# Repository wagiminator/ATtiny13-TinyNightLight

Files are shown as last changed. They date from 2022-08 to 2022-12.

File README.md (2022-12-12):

# TinyNightLight - Night Light with NeoPixels
TinyNightLight is a rotary encoder controlled and battery powered nightlight with NeoPixels based on the ATtiny13A.

- Design Files (EasyEDA): https://easyeda.com/wagiminator/attiny13-tinynightlight_copy

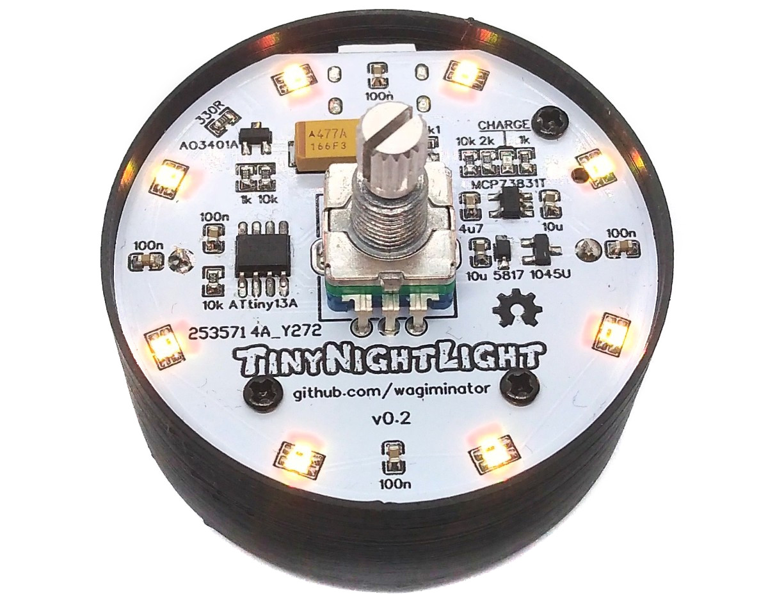
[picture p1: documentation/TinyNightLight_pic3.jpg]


# Hardware
## Schematic
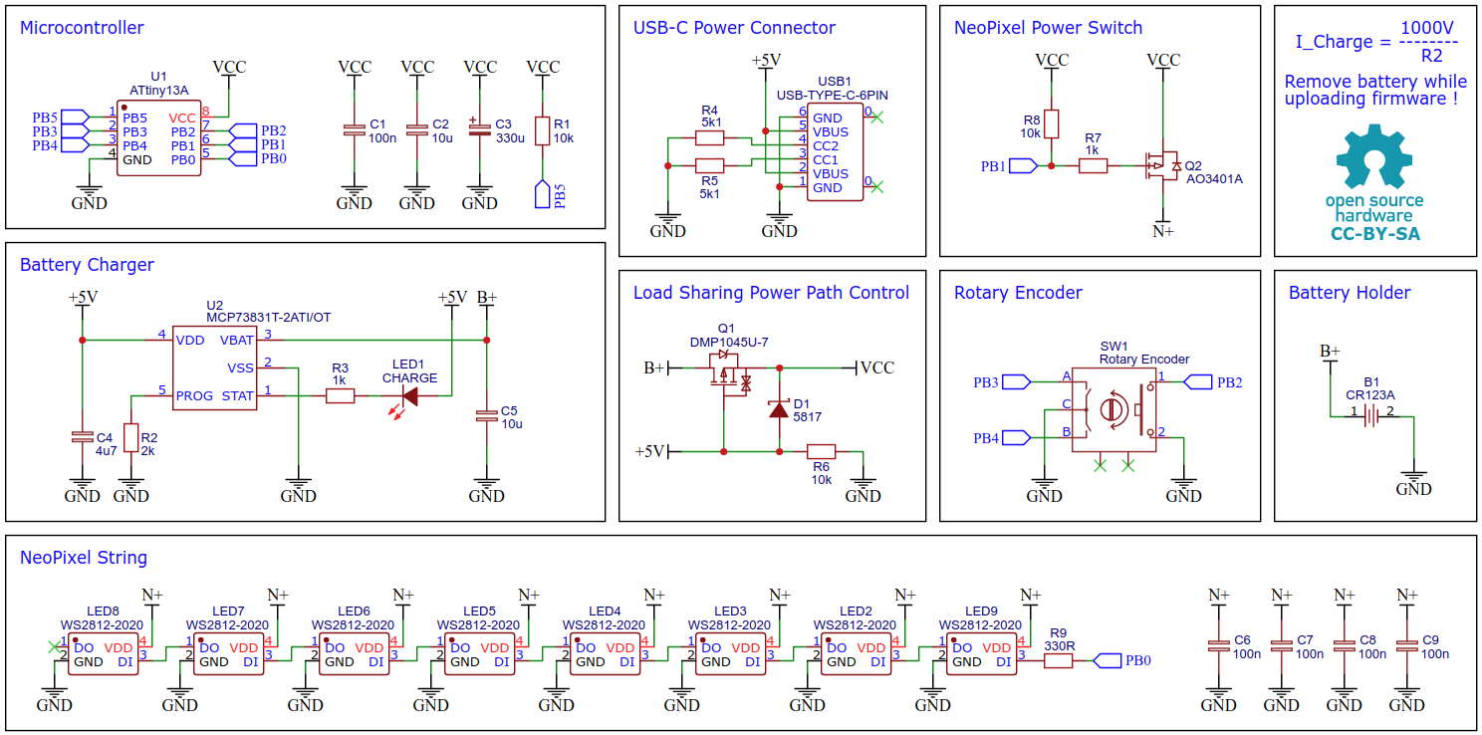
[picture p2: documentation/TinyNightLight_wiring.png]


## WS2812 Addressable LEDs
WS2812-2020 is an intelligent control LED light source, which integrates the control circuit and RGB chip in a small 2020 package. It internally contains an intelligent digital port data latch, a signal conditioning gain driver circuit, a precision oscillator and a voltage-programmable constant current control part, which effectively ensures that the pixel point light color level is consistent. Make sure you use the 5mA variant.

## MCP73831 Li-Ion Battery Charger IC
For battery charging the MCP73831 is used. The MCP73831 is a highly advanced linear charge management controller for use in space-limited, cost-sensitive applications. It employs a constant-current/constant-voltage charge algorithm with selectable preconditioning and charge termination. The constant current value is set with one external resistor (I = 1000V / R2). Charging is done via the built-in USB-C connector. The MCP73831 can be replaced by the much cheaper TP4054 without further modifications.

## Power Path Control
The device can be operated both by battery and external power. The load sharing power path control system interrupts the connection between the battery and the load when an external power supply is connected. In this case, the device is powered by the external power supply while the battery is being charged. This protects the battery and increases its lifespan. Without an external power supply, the device is powered directly by the battery.

# Software
## NeoPixel Implementation
The NeoPixel implementation is based on [NeoController](https://github.com/wagiminator/ATtiny13-NeoController).

## Compiling and Uploading the Firmware
Since there is no ICSP header on the board, you have to program the ATtiny either before soldering using an [SOP adapter](https://aliexpress.com/wholesale?SearchText=sop-8+150mil+adapter), or after soldering using an [EEPROM clip](https://aliexpress.com/wholesale?SearchText=sop8+eeprom+programming+clip). The [AVR Programmer Adapter](https://github.com/wagiminator/AVR-Programmer/tree/master/AVR_Programmer_Adapter) can help with this. Remove the battery before connecting the device to the programmer.

### If using the Arduino IDE
- Make sure you have installed [MicroCore](https://github.com/MCUdude/MicroCore).
- Go to **Tools -> Board -> MicroCore** and select **ATtiny13**.
- Go to **Tools** and choose the following board options:
  - **Clock:**  9.6 MHz internal osc.
  - **BOD:**    BOD 2.7V
  - **Timing:** Micros disabled
- Connect your programmer to your PC and to the ATtiny.
- Go to **Tools -> Programmer** and select your ISP programmer (e.g. [USBasp](https://aliexpress.com/wholesale?SearchText=usbasp)).
- Go to **Tools -> Burn Bootloader** to burn the fuses.
- Open the TinyNightLight sketch and click **Upload**.

### If using the precompiled hex-file
- Make sure you have installed [avrdude](https://learn.adafruit.com/usbtinyisp/avrdude).
- Connect your programmer to your PC and to the ATtiny.
- Open a terminal.
- Navigate to the folder with the hex-file.
- Execute the following command (if necessary replace "usbasp" with the programmer you use):
  ```
  avrdude -c usbasp -p t13 -U lfuse:w:0x3a:m -U hfuse:w:0xfb:m -U flash:w:tinynightlight.hex
  ```

### If using the makefile (Linux/Mac)
- Make sure you have installed [avr-gcc toolchain and avrdude](http://maxembedded.com/2015/06/setting-up-avr-gcc-toolchain-on-linux-and-mac-os-x/).
- Connect your programmer to your PC and to the ATtiny.
- Open a terminal.
- Navigate to the folder with the makefile and the sketch.
- Run `PROGRMR=usbasp make install` to compile, burn the fuses and upload the firmware (change PROGRMR accordingly).

# Operating Instructions
Place a 3.7V protected 16340 (LR123A) Li-Ion battery in the holder. The battery can be charged via the USB-C port. A red LED lights up during charging. It goes out when charging is complete.

The device has four different states, which can be switched between by pressing the rotary encoder button.

|State|Description|
|:-|:-|
|0|All LEDs are off and the ATtiny is in sleep mode.|
|1|All LEDs light up white. The brightness can be changed by turning the rotary encoder. The brightness set by this is also retained for the following states.|
|2|The LEDs show a color animation with the previously set brightness. The speed of the animation can be adjusted using the rotary encoder.|
|3|All LEDs show the same color with the previously set brightness. The color can be changed by turning the rotary encoder.|

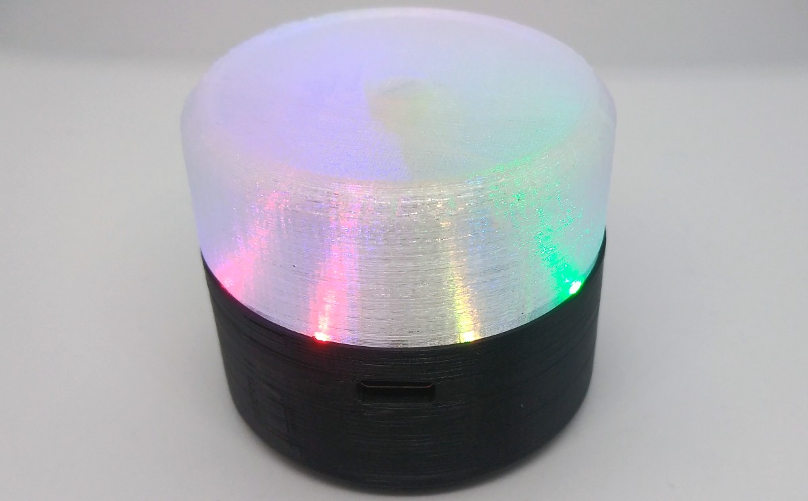
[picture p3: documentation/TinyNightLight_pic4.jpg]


# References, Links and Notes
1. [ATtiny13A Datasheet](http://ww1.microchip.com/downloads/en/DeviceDoc/doc8126.pdf)
2. [WS2812-2020 Datasheet](https://www.led-stuebchen.de/download/WS2812-2020_V1.1_EN.pdf)
3. [MCP73831 Datasheet](https://datasheet.lcsc.com/lcsc/1809191822_Microchip-Tech-MCP73831T-2ATI-OT_C14879.pdf)
4. [NeoPixel Implementation](https://github.com/wagiminator/ATtiny13-NeoController)

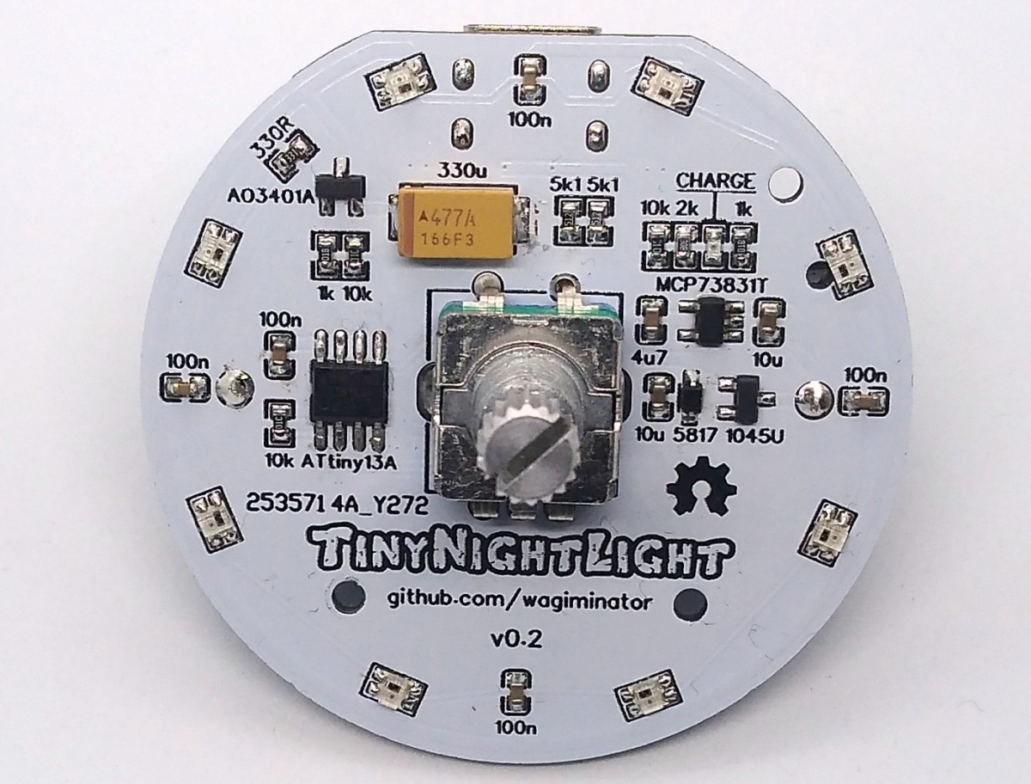
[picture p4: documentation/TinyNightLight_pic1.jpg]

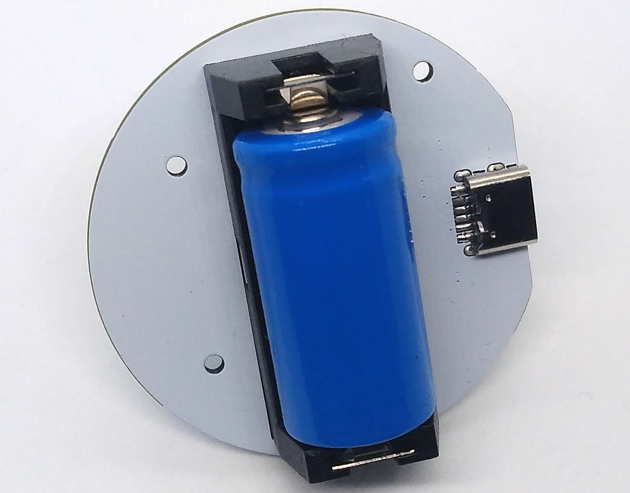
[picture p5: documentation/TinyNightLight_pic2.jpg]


# License


This work is licensed under Creative Commons Attribution-ShareAlike 3.0 Unported License. 
(http://creativecommons.org/licenses/by-sa/3.0/)

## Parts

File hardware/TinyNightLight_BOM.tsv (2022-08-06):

ID | Name | Designator | Footprint | Quantity | Manufacturer Part | Manufacturer | Supplier | Supplier Part | Price
1 | CR123A | B1 | TH_L43.0-W-18.0-CR123A | 1 | CR123A电池座 | null | LCSC | C2803347
2 | 100n | C1,C6,C7,C8,C9 | C_0603 | 5 | CC0603KRX7R9BB104 | YAGEO | LCSC | C14663 | 0.002
3 | 10u | C2,C5 | C_0603 | 2 | CL10A106MA8NRNC | SAMSUNG | LCSC | C96446 | 0.013
4 | 330u | C3 | TANTALUM_CASE-D | 1 | TAJD337M010RNJ | AVX | LCSC | C105408 | 0.936
5 | 4u7 | C4 | C_0603 | 1 | CL10A475KA8NQNC | SAMSUNG | LCSC | C69335 | 0.019
6 | 5817 | D1 | SCHOTTKY_SOD_323 | 1 | 1N5817WS | TWGMC | LCSC | C727114 | 0.028
7 | CHARGE | LED1 | LED0603 | 1 | KT-0603R | KENTO | LCSC | C2286
8 | WS2812-2020 | LED2,LED3,LED4,LED5,LED6,LED7,LED8,LED9 | WS2812-2020 | 8 | WS2812C-2020 | worldsemi | LCSC | C965556 | 0.12
9 | DMP1045U-7 | Q1 | SOT-23-3_W | 1 | DMP1045U-7 | Diodes Incorporated | LCSC | C177033 | 0.151
10 | AO3401A | Q2 | SOT-23-3_W | 1 | AO3401A | HUASHUO(华朔) | LCSC | C700954 | 0.036
11 | 10k | R1,R6,R8 | 0603 | 3 | 0603WAF1002T5E | UniOhm | LCSC | C25804
12 | 2k | R2 | 0603 | 1 | 0603WAF2001T5E | UniOhm | LCSC | C22975 | 0.001
13 | 1k | R3,R7 | 0603 | 2 | 0603WAF1001T5E | UniOhm | LCSC | C21190
14 | 5k1 | R4,R5 | 0603 | 2 | 0603WAF5101T5E | UniOhm | LCSC | C23186 | 0.001
15 | 330R | R9 | 0603 | 1 | 0603WAF3300T5E | UniOhm | LCSC | C23138 | 0.001
16 | Rotary Encoder | SW1 | ROTARY_ENCODER | 1 | PEC11R-4015F-S0024 | BOURNS | LCSC | C143789 | 1.492
17 | ATtiny13A | U1 | SOP-8_150MIL | 1 | ATTINY13A-SSU | MICROCHIP | LCSC | C14075 | 1.913
18 | MCP73831T-2ATI/OT | U2 | SOT-23-5_BR | 1 | MCP73831T-2ATI/OT | MICROCHIP | LCSC | C14879 | 1.846
19 | USB-TYPE-C-6PIN | USB1 | USB-C-SMD-6P | 1 | TYPE-C-31-M-17 | Korean Hroparts Elec | LCSC | C283540 | 0.204

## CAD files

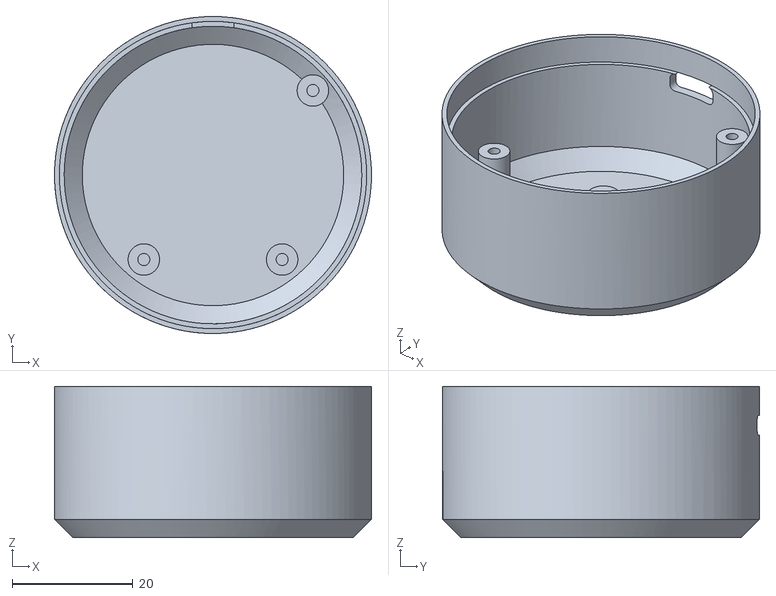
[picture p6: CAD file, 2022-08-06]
3dprint/TinyNightLight_case_bottom.stl
52.4 x 52.4 x 25.0

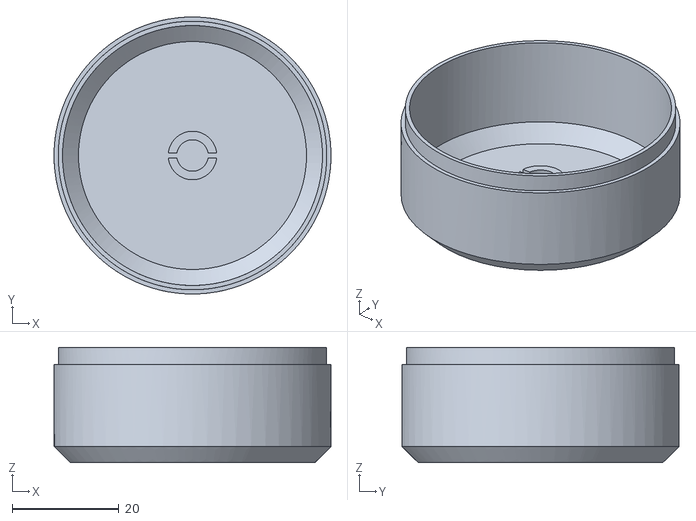
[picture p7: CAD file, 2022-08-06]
3dprint/TinyNightLight_case_top.stl
52.0 x 52.0 x 21.6

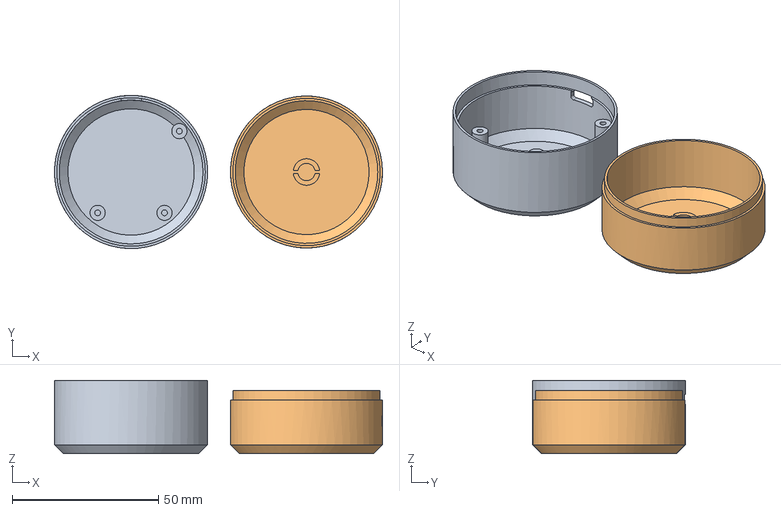
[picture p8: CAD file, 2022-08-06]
3dprint/TinyNightLight_case.fcstd
112.2 x 52.4 x 25.0 mm
Bottom
Top

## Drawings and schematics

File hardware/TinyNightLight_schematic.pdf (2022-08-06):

# VCC PB⁵

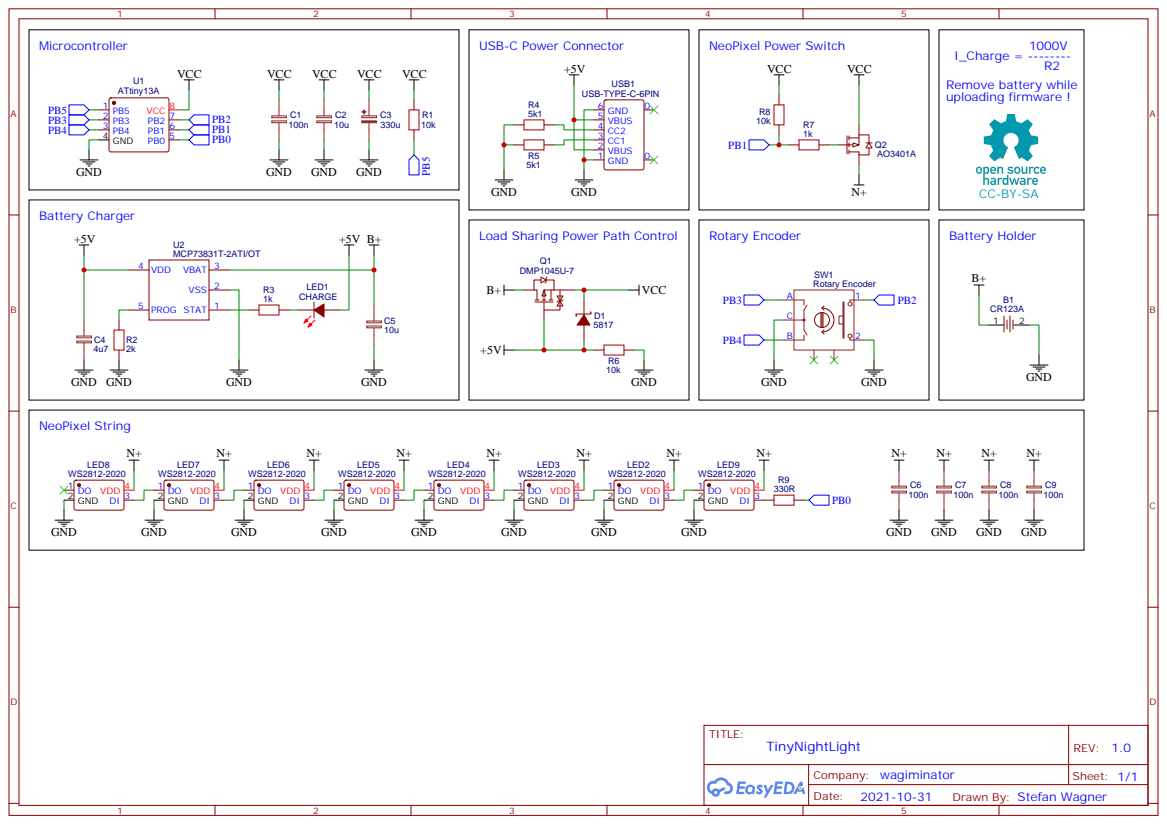
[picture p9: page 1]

Load Sharing Power Path Control

Drawn By: Stefan Wagner

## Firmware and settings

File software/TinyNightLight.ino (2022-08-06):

// ===================================================================================
// Project:   TinyNightLight - Night Light with NeoPixels based on ATtiny13A
// Version:   v1.0
// Year:      2021
// Author:    Stefan Wagner
// Github:    https://github.com/wagiminator
// EasyEDA:   https://easyeda.com/wagiminator
// License:   http://creativecommons.org/licenses/by-sa/3.0/
// ===================================================================================
//
// Description:
// ------------
// Rotary encoder controlled and battery powered nightlight with NeoPixels.
//
// References:
// -----------
// The Neopixel implementation is based on NeoController.
// https://github.com/wagiminator/ATtiny13-NeoController
//
// Wiring:
// -------
//                              +-\/-+
//           --- RST ADC0 PB5  1|°   |8  Vcc
// ENCODER A ------- ADC3 PB3  2|    |7  PB2 ADC1 -------- ENCODER SW
// ENCODER B ------- ADC2 PB4  3|    |6  PB1 AIN1 OC0B --- MOSFET
//                        GND  4|    |5  PB0 AIN0 OC0A --- NEOPIXELS
//                              +----+
//
// Compilation Settings:
// ---------------------
// Controller:  ATtiny13A
// Core:        MicroCore (https://github.com/MCUdude/MicroCore)
// Clockspeed:  9.6 MHz internal
// BOD:         BOD disabled
// Timing:      Micros disabled
//
// Leave the rest on default settings. Don't forget to "Burn bootloader"!
// No Arduino core functions or libraries are used. Use the makefile if 
// you want to compile without Arduino IDE.
// Remove the battery before connecting the device to the programmer.
//
// Fuse settings: -U lfuse:w:0x3a:m -U hfuse:w:0xff:m
//
// Operating Instructions:
// -----------------------
// Place a 3.7V protected 16340 (LR123A) Li-Ion battery in the holder. The battery
// can be charged via the USB-C port. A red LED lights up during charging. It goes
// out when charging is complete.
// The device has four different states, which can be switched between by pressing
// the rotary encoder button.
// In state 0, all LEDs are off and the ATtiny is in sleep mode.
// In state 1, all LEDs light up white. The brightness can be changed by turning
// the rotary encoder. The brightness set by this is also retained for the
// following states.
// In state 2, the LEDs show a color animation with the previously set brightness.
// The speed of the animation can be adjusted using the rotary encoder.
// In state 3, all LEDs show the same color with the previously set brightness. The
// color can be changed by turning the rotary encoder.


// ===================================================================================
// Libraries and Definitions
// ===================================================================================

// Libraries
#include <avr/io.h>           // for GPIO
#include <avr/sleep.h>        // for sleep functions
#include <avr/interrupt.h>    // for interrupts
#include <util/delay.h>       // for delays

// Pin definitions
#define PIN_NEO       PB0     // pin connected to DIN of neopixels
#define PIN_ENABLE    PB1     // pin connected to MOSFET to switch on/off neopixels
#define PIN_ENC_SW    PB2     // pin connected to rotary encoder switch
#define PIN_ENC_A     PB3     // pin connected to rotary encoder A
#define PIN_ENC_B     PB4     // pin connected to rotary encoder B

// Pin manipulation macros
#define pinInput(x)   DDRB  &= ~(1<<(x))        // set pin to INPUT
#define pinOutput(x)  DDRB  |=  (1<<(x))        // set pin to OUTPUT
#define pinLow(x)     PORTB &= ~(1<<(x))        // set pin to LOW
#define pinHigh(x)    PORTB |=  (1<<(x))        // set pin to HIGH
#define pinPullup(x)  PORTB |=  (1<<(x))        // enable PULLUP resistor
#define pinIntEn(x)   PCMSK |=  (1<<(x))        // enable pin change interrupt
#define pinIntDis(x)  PCMSK &= ~(1<<(x))        // disable pin change interrupt
#define pinRead(x)    (PINB &   (1<<(x)))       // READ pin

// ===================================================================================
// Low-Level Neopixel Implementation for 9.6 MHz MCU Clock and 800 kHz Pixels
// ===================================================================================

// NeoPixel parameter and macros
#define NEO_init()    pinOutput(PIN_NEO)        // set pixel DATA pin as output
#define NEO_on()      pinOutput(PIN_ENABLE)     // switch on neopixels
#define NEO_off()     pinInput(PIN_ENABLE)      // switch off neopixels
#define NEO_latch()   _delay_us(281)            // delay until bytes are latched

// Send a byte to the pixels string
void NEO_sendByte(uint8_t byte) {               // CLK  comment
  for(uint8_t bit=8; bit; bit--) asm volatile(  //  3   8 bits, MSB first
    "sbi  %[port], %[pin]   \n\t"               //  2   DATA HIGH
    "sbrs %[byte], 7        \n\t"               // 1-2  if "1"-bit skip next instruction
    "cbi  %[port], %[pin]   \n\t"               //  2   "0"-bit: DATA LOW after 3 cycles
    "rjmp .+0               \n\t"               //  2   delay 2 cycles
    "add  %[byte], %[byte]  \n\t"               //  1   byte <<= 1
    "cbi  %[port], %[pin]   \n\t"               //  2   "1"-bit: DATA LOW after 7 cycles
    ::
    [port]  "I"   (_SFR_IO_ADDR(PORTB)),
    [pin]   "I"   (PIN_NEO),
    [byte]  "r"   (byte)
  );
}

// Write color to a single pixel
void NEO_writeColor(uint8_t r, uint8_t g, uint8_t b) {
  cli();
  NEO_sendByte(g); NEO_sendByte(r); NEO_sendByte(b);
  sei();
}

// Square function
uint8_t sqr(uint8_t x) {
  uint8_t result = 0;
  for(uint8_t i=x; i; i--) result += x;
  return result;
}

// Write hue value (0..47) and brightness (0..15) to a single pixel
void NEO_writeHue(uint8_t hue, uint8_t bright) {
  uint8_t phase = hue >> 4;
  hue          &= 15;
  bright        = (15 - bright) >> 1;
  uint8_t step  = (sqr(hue) >> bright) + 1;
  uint8_t nstep = (sqr(15 - hue) >> bright) + 1;
  switch(phase) {
    case 0:   NEO_writeColor(nstep,  step,     0); break;
    case 1:   NEO_writeColor(    0, nstep,  step); break;
    case 2:   NEO_writeColor( step,     0, nstep); break;
    default:  break;
  }
}

// Set a single pixel to white with brightness (0..15);
void NEO_writeWhite(uint8_t bright) {
  bright = sqr(bright);                         // simple gamma correction
  NEO_writeColor(bright, bright, bright);       // write to pixel
}

// ===================================================================================
// Rotary Encoder Implementation using Pin Change Interrupt
// ===================================================================================

// Global variables
volatile uint8_t  ENC_a0, ENC_b0, ENC_ab0, ENC_loop;
volatile int16_t  ENC_count, ENC_countMin, ENC_countMax, ENC_countStep;

// Init rotary encoder
void ENC_init(void) {
  pinPullup(PIN_ENC_A);                         // enable pullup on encoder pins ...
  pinPullup(PIN_ENC_B);
  pinPullup(PIN_ENC_SW);
  pinIntEn(PIN_ENC_A);                          // enable pin change interrupt on ENC A
  ENC_a0  = !pinRead(PIN_ENC_A);                // set initial values ...
  ENC_b0  = !pinRead(PIN_ENC_B);
  ENC_ab0 = (ENC_a0 == ENC_b0);
  GIMSK  |= (1<<PCIE);                          // enable pin change interrupts
}

// Set parameters for rotary encoder
void ENC_set(int16_t rmin, int16_t rmax, int16_t rstep, int16_t rvalue, uint8_t rloop) {
  ENC_countMin  = rmin << 1;                    // min value
  ENC_countMax  = rmax << 1;                    // max value
  ENC_countStep = rstep;                        // count steps (negative if CCW)
  ENC_count     = rvalue << 1;                  // actual count value
  ENC_loop      = rloop;                        // loop if true
}

// reads current rotary encoder value
int ENC_get(void) {
  return(ENC_count >> 1);
}

// Pin change interrupt service routine for rotary encoder
ISR(PCINT0_vect) {
  uint8_t a = !pinRead(PIN_ENC_A);
  uint8_t b = !pinRead(PIN_ENC_B);
  if(a != ENC_a0) {                             // A changed?
    ENC_a0 = a;
    if(b != ENC_b0) {                           // B changed?
      ENC_b0 = b;
      ENC_count += (a == b) ? -ENC_countStep : ENC_countStep;
      if((a == b) != ENC_ab0) ENC_count += (a == b) ? -ENC_countStep : ENC_countStep;
      if(ENC_count < ENC_countMin) ENC_count = (ENC_loop) ? ENC_countMax : ENC_countMin;
      if(ENC_count > ENC_countMax) ENC_count = (ENC_loop) ? ENC_countMin : ENC_countMax;
      ENC_ab0 = (a == b);
    }
  }
}

// ===================================================================================
// Main Function
// ===================================================================================

int main(void) {
  // Local variables
  uint8_t state   = 0;                          // aninmation state
  uint8_t hue     = 0;                          // hue
  uint8_t bright  = 5;                          // brightness
  uint8_t anim    = 0;                          // animation state
  uint8_t counter = 8;                          // animation delay counter
  uint8_t huey;                                 // temp

  // Disable unused peripherals and prepare sleep mode to save power
  ACSR   =  (1<<ACD);                           // disable analog comparator
  PRR    =  (1<<PRADC)|(1<<PRTIM0);             // shut down ADC and timer0
  set_sleep_mode(SLEEP_MODE_PWR_DOWN);          // set sleep mode to power down

  // Setup
  NEO_init();                                   // init neopixels
  ENC_init();                                   // init rotary encoder
  pinIntEn(PIN_ENC_SW);                         // enable pin change interrupt on ENC SW
  sei();                                        // enable interrupts

  // Loop
  while(1) {
    // State machine - remain state until encoder switch is pressed
    while(pinRead(PIN_ENC_SW)) {
      switch(state) {
        // State 0: device is in sleep mode
        case 0:   sleep_mode();                 // sleep until rotary button pressed
                  break;

        // State 1: device shows white LEDs; brightness can be adjusted via encoder
        case 1:   bright = ENC_get();           // get brightness from encoder
                  for(uint8_t i=8; i; i--)      // set all 8 pixels ...
                    NEO_writeWhite(bright);     // ... to white at specified brightness
                  NEO_latch();                  // latch the pixels
                  break;

        // State 2: device shows color animation; speed can be adjusted
        case 2:   if(!--counter) {                // time for next animation step?
                    huey = anim;                  // get hue for first pixel
                    for(uint8_t i=8; i; i--) {    // set all 8 pixels ...
                      NEO_writeHue(huey, bright); // ... to a different color
                      huey += 6;                  // color step 6 (48/8)
                      if(huey > 47) huey -= 48;   // make sure it's a color ring
                    }
                    if(++anim > 47) anim = 0;     // shift starting color for next step
                    counter = ENC_get();          // get animation speed from encoder
                  }
                  _delay_ms(21);                  // a little delay; also latch
                  break;

        // State 3: device shows one color that can be adjusted
        case 3:   hue = ENC_get();              // get hue from encoder
                  for(uint8_t i=8; i; i--)      // set all 8 pixels ...
                    NEO_writeHue(hue, bright);  // ... to the specified hue
                  NEO_latch();                  // latch the pixels
                  break;
        default:  break;
      }
    }

    // Encoder switch pressed - wait until released
    _delay_ms(10);                              // debounce
    while(!pinRead(PIN_ENC_SW));                // wait for button to be released
    _delay_ms(10);                              // debounce

    // Change state after encoder switch was pressed
    if(++state > 3) state = 0;                  // next state
    switch(state) {
      case 0:     NEO_off();                    // switch off neopixels
                  break;
      case 1:     NEO_on();                     // switch on neopixels
                  ENC_set(2, 15, 1, bright, 0); // set rotary encoder
                  break;
      case 3:     ENC_set(0, 48, 1, hue, 1);    // set rotary encoder
                  break;
      default:    break;
    }
  }
}
